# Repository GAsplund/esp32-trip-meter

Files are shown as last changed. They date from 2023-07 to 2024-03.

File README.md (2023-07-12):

# ESP32 Trip Meter
An ESP32-based trip meter primarily made for measuring fuel efficiency.

## Background and motivation
I started this project in search of a solution for measuring the fuel efficiency on my '97 Volvo 940.
The only real solution I found prior was the [MPGuino](http://mpguino.wiseman.ee/eng), but I quickly realised it wasn't for my needs.
What I wanted was to have a solution that was as clean as possible, so having a separate display that I had to mount somewhere was out of the question.

Instead, I built it around a standard Bluetooth OBD-II interface, which would allow any device to get information and display it in any way they want.
This was perfect for my use case, as I wanted to display all the information on my phone or Android stereo via the [Torque](https://play.google.com/store/apps/details?id=org.prowl.torque) app.

## Features
- Measure fuel efficiency (L/100km)
- Measure velocity (Km/h)
- Measure fuel injection speed (L/h)
- Display data through an emulated ELM327 (OBD-II) interface

## Connections
- The negative side of the injector is connected to corresponding input on the board
  - NOTE: Must be a saturation-type injector (read below)
- A pulsed signal of the vehicle speed sensor (VSS) is connected to VSS+
  - Variable reluctance (VR) speed sensors do not seem to work

### Power and ground
The ground reference and power is currently given by the USB port on the ESP32.
This may change later due to being a limiting factor.

## Injector types
This project is mainly made to support saturation-type injectors.
If your engine uses other types of injectors, such as peak-and-hold injectors, this project **will not work**.

The easiest way to check this is to measure the resistance of an injector;
If it has a resistance of around 12Ω, it is a saturation-type injector.
If it has a resistance of around 2-3Ω, it is likely a **peak-and-hold** injector.

**Also note that** injectors that are connected for batch injection may be connected in parallel, and may in some cases display a resistance that is lower than normal.

The reason why peak-and-hold injectors will not work, is that they work differently from saturation injectors.
While saturation injectors simply open while the signal is active, a peak-and-hold injector, like its name suggests, sends a high voltage signal which forces the injector open (peak).
After that, a lower-voltage signal (normally around 12 volts) is pulsed through the remainder of the opening time (hold).

## Platform compatibility
Since the project currently uses ESP32-specific platform code a lot, it would be difficult to port to using normal Arduino implementations.
It may be possible to port it to ESP8266 devices, but they would need a discrete Bluetooth module.

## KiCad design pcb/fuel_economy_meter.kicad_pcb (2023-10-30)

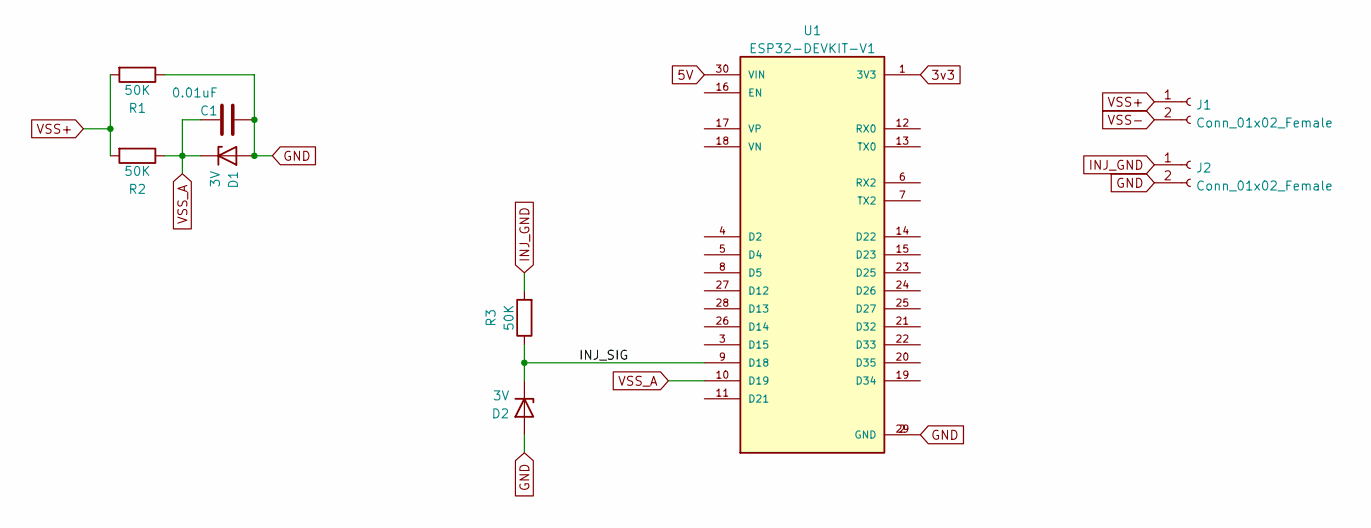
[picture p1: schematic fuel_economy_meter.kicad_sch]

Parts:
C1: 0.01uF; C_1206_3216Metric_Pad1.33x1.80mm_HandSolder
D1, D2: 3V; D_SOD-123
J1, J2: Conn_01x02_Female; JST_XH_B2B-XH-A_1x02_P2.50mm_Vertical
R1, R2, R3: 50K; R_1206_3216Metric_Pad1.30x1.75mm_HandSolder
U1: ESP32-DEVKIT-V1; MODULE_ESP32_DEVKIT_V1; PARTREV N/A

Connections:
3v3: U1.1 (3V3)
5V: U1.30 (VIN)
/INJ_SIG: D2.1 (K), R3.1, U1.9 (D18)
GND: C1.2, D1.2 (A), D2.2 (A), J2.2, R1.1, U1.2 (GND), U1.29 (GND)
INJ_GND: J2.1, R3.2
VSS+: J1.1, R1.2, R2.2
VSS-: J1.2
VSS_A: C1.1, D1.1 (K), R2.1, U1.10 (D19)

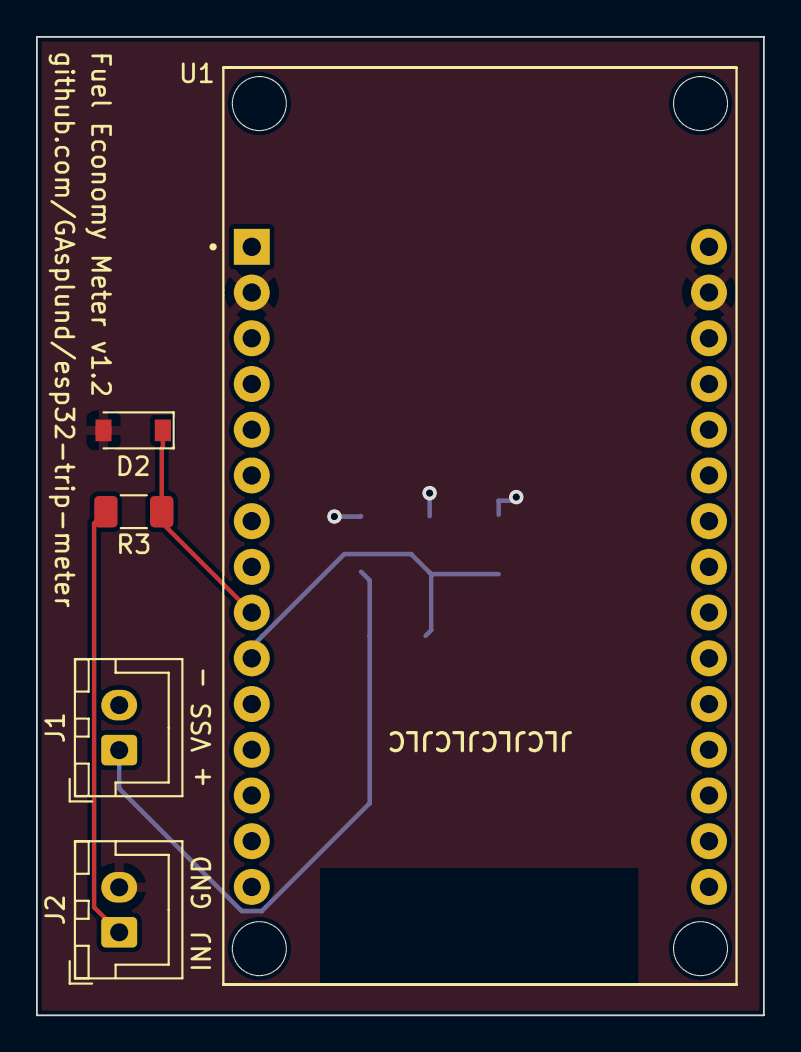
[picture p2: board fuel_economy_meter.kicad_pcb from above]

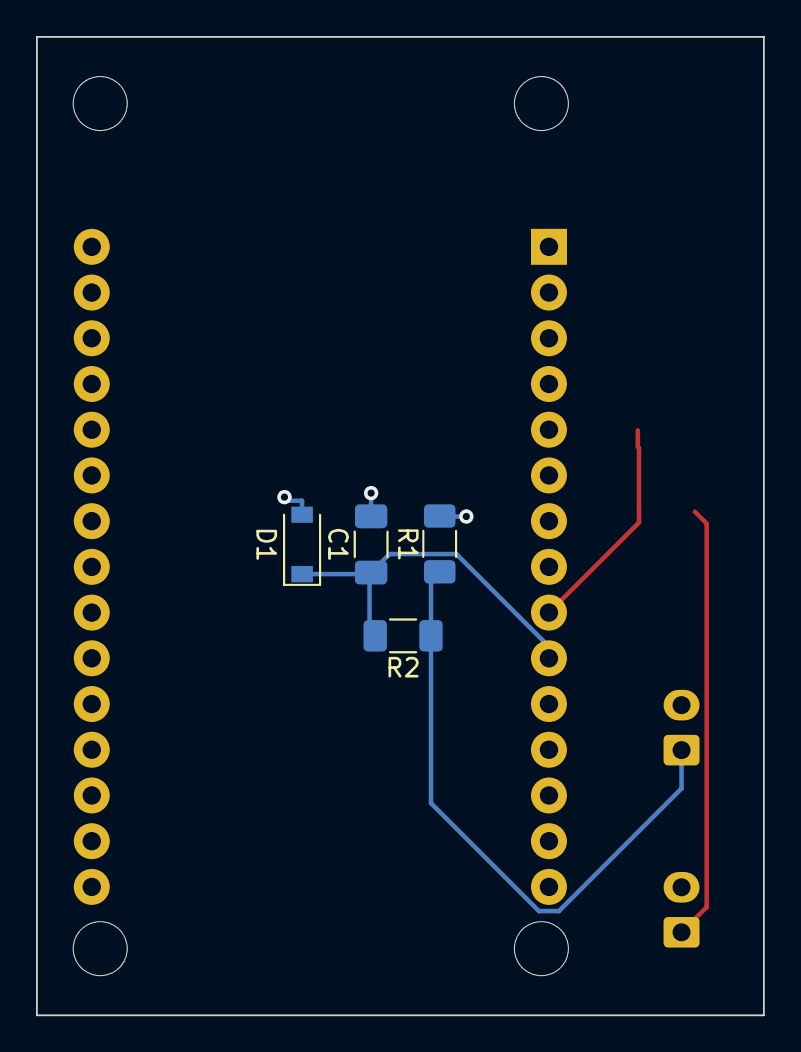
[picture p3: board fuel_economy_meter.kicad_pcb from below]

Board: 2 copper layers, 40.4 x 54.4 mm, 9 parts (4 on the bottom side), 5 nets.

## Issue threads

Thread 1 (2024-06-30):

Esp32 crashes after couple seconds of reading

gangster-unicorn, 2024-06-30:
Im currently Testing this in on my old but trusted bmw r1200gs from 2004. I'm printing the readings via the Logstream function. Its looks like its reading the injector fine. When i give gas the L/h starts rising. But after about 1 minute of reading it looks like the esp32 crashes and i have to cycle the power to get it to start logging again. Any thoughts? I'm using the esp32 wroom

GAsplund, 2024-06-30:
Hi, thanks for testing it out! I've been developing on an ESP32-wroom myself, so differing hardware should not be an issue.

Regarding the freeze, it sounds like the watchdog is triggering for some reason. Previous times where I've had this happen it would crash and require a manual reset. You can try checking if this is the case for you by using a baud rate of 115200 and running until it crashes or freezes. Hopefully it will print a stacktrace showing what's wrong.

gangster-unicorn, 2024-06-30:
Hi, thanks for the fast response.

Somehow changing the baudrate to 115200 its not crashing anymore. thanks for helping me out! One more question, i notice that a lot of the time it does not register the rpm only the injection time. Is this expected behaviour?

GAsplund, 2024-06-30:
My guess is that a lower baud rate causes printing along with the interrupts to starve the watchdog timer. Glad to hear that increasing it solved the issue!
The calculation for RPM should work as long as the injectors are being measured properly. If the injection period changes at all between prints, that should be the case.

gangster-unicorn, 2024-07-04:
Thanks for all the help turns out i was using the wrong zener diodes 5v instead of 3v now everything works properly!

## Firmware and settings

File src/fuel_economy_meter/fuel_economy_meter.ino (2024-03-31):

#include "trip.h"
#include "bt.h"
#include "elm327.h"
#include "log_stream.h"

static Trip trip;
static ELM327 elm327;
//static LogStream logStream;

void setup()
{
  Serial.begin(9600);
  Serial.println("BT");
  setupBT();
  Serial.println("Trip");
  trip.begin();
  elm327.begin(&SerialBT, &trip);
  //Serial.println("LogStream");
  //logStream.begin(&Serial, &trip);

  Serial.println("Setup done");
}

void loop()
{
  //delay(1000);
  //logStream.log();
  elm327.poll();
}

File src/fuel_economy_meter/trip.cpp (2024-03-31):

#include "trip.h"

#include <arduino.h>
#include "esp_timer.h"
#include "config.h"
#include "soc/mcpwm_reg.h"
#include "soc/mcpwm_struct.h"
#include "driver/mcpwm.h"
#include "driver/timer.h"

#define APB_TICK_US(ticks) ((ticks) / (APB_CLK_FREQ / 1000000))

Trip *sTrip = 0;

/**
 * Starts the VSS interrupts and adds interrupts for the injector and VSS sensor
 */
void Trip::begin(void)
{
  sTrip = this;

  Serial.println("Setting up timers");
  timer_init(TIMER_GROUP_0, TIMER_0, &timeout_timer_conf);
  timer_init(TIMER_GROUP_0, TIMER_1, &timeout_timer_conf);
  timer_set_counter_value(TIMER_GROUP_0, TIMER_0, INJ_TICKS_TIMEOUT);
  timer_set_counter_value(TIMER_GROUP_0, TIMER_1, VSS_TICKS_TIMEOUT);
  timer_isr_callback_add(TIMER_GROUP_0, TIMER_0, &Trip::timeoutInjISR, NULL, 0);
  timer_isr_callback_add(TIMER_GROUP_0, TIMER_1, &Trip::timeoutVssISR, NULL, 0);

  Serial.println("Setting up injector ISR");
  gpio_set_pull_mode(INJ_GPIO, GPIO_PULLUP_ONLY);
  mcpwm_gpio_init(MCPWM_UNIT_0, MCPWM_CAP_0, INJ_GPIO);
  mcpwm_gpio_init(MCPWM_UNIT_0, MCPWM_CAP_1, INJ_GPIO);
  mcpwm_capture_enable(MCPWM_UNIT_0, MCPWM_SELECT_CAP0, MCPWM_NEG_EDGE, 0);
  mcpwm_capture_enable(MCPWM_UNIT_0, MCPWM_SELECT_CAP1, MCPWM_POS_EDGE, 0);
  mcpwm_isr_register(MCPWM_UNIT_0, Trip::tripInjISRHandler, NULL, ESP_INTR_FLAG_IRAM, NULL);

  Serial.println("Setting up VSS ISR");
  gpio_set_pull_mode(VSS_GPIO, GPIO_PULLUP_ONLY);
  mcpwm_gpio_init(MCPWM_UNIT_1, MCPWM_CAP_0, VSS_GPIO);
  mcpwm_gpio_init(MCPWM_UNIT_1, MCPWM_CAP_1, VSS_GPIO);
  mcpwm_capture_enable(MCPWM_UNIT_1, MCPWM_SELECT_CAP0, MCPWM_NEG_EDGE, 0);
  mcpwm_capture_enable(MCPWM_UNIT_1, MCPWM_SELECT_CAP1, MCPWM_POS_EDGE, 0);
  mcpwm_isr_register(MCPWM_UNIT_1, Trip::tripVssISRHandler, NULL, ESP_INTR_FLAG_IRAM, NULL);

  Serial.println("Starting timers");
  timer_start(TIMER_GROUP_0, TIMER_0);
  timer_start(TIMER_GROUP_0, TIMER_1);
}

/**
 * @brief Handles a pulse in the injector signal
 *
 * Used to calculate total and momentary injection time.
 * Injector is considered open when the signal is low due to MOSFET pulling it down.
 * 
 *     ╭―(+ Inj -)―╮
 *     +           o - pull-down signal
 *     |           |
 *     -           / - ECU MOSFET
 *     ╰―――――――――――╯
 */
void Trip::injPulse(uint32_t openCap, uint32_t closeCap)
{
  timer_set_counter_value(TIMER_GROUP_0, TIMER_0, INJ_TICKS_TIMEOUT);

  // Make sure that the injector has been open before
  // We also don't know how many times we could have 
  // overflowed before, so we discard any additional captures
  if (this->latestInjectionTimestamp == 0)
  {
    this->latestInjectionTimestamp = openCap;
    return;
  }

  uint32_t dutyTime = openCap > closeCap ?
    (0xFFFFFFFF - openCap) + closeCap + 1:
    closeCap - openCap;

  if (dutyTime <= INJ_DELTA_MAX)
  {
    this->latestInjectionDutyTime = APB_TICK_US(dutyTime);
    this->latestInjectionPeriod = APB_TICK_US(openCap - this->latestInjectionTimestamp);
  }
  
  this->latestInjectionTimestamp = openCap;
}

void IRAM_ATTR Trip::tripInjISRHandler(void* arg)
{
  if (MCPWM0.int_st.cap1_int_st && sTrip != 0)
    sTrip->injPulse(mcpwm_capture_signal_get_value(MCPWM_UNIT_0, MCPWM_SELECT_CAP0), mcpwm_capture_signal_get_value(MCPWM_UNIT_0, MCPWM_SELECT_CAP1));
  
  MCPWM0.int_clr.val = MCPWM0.int_st.val;
}

/**
 * @brief Handles a pulse in the VSS signal
 *
 * Uses the length of the pulse to calculate the velocity of the vehicle.
 * If the time since the last pulse isn't too long, the pulse is considered to be valid.
 */
void Trip::vssPulse(uint32_t upCap, uint32_t downCap)
{
  timer_set_counter_value(TIMER_GROUP_0, TIMER_1, VSS_TICKS_TIMEOUT);
  this->totalVssPulses++;

  if(isStopped)
  {
    isStopped = false;
    return;
  }

  // We assume that the HIGH time is always half a period
  uint32_t period = 2 * (upCap > downCap ?
    (0xFFFFFFFF - upCap) + downCap + 1:
    downCap - upCap);

  if (period < VSS_DELTA_MAX)
    this->latestVssPeriod = APB_TICK_US(period);
}

void IRAM_ATTR Trip::tripVssISRHandler(void* arg)
{
  if (MCPWM1.int_st.cap1_int_st && sTrip != 0)
    sTrip->vssPulse(mcpwm_capture_signal_get_value(MCPWM_UNIT_1, MCPWM_SELECT_CAP0), mcpwm_capture_signal_get_value(MCPWM_UNIT_1, MCPWM_SELECT_CAP1));
  
  MCPWM1.int_clr.val = MCPWM1.int_st.val;
}

/**
 * @brief Handles a timeout in the injector signal
 *
 * Used to calculate the total RPM of the engine.
 * If the injector has not opened for a long time, the engine is considered to be stopped.
 */
void Trip::timeoutInj()
{
  this->latestInjectionPeriod = 0;
  this->latestInjectionDutyTime = 0;
  this->latestInjectionTimestamp = 0;
}

bool IRAM_ATTR Trip::timeoutInjISR(void*)
{
  Serial.println("Inj timeout");
  if (sTrip != 0)
    sTrip->timeoutInj();
  return false;
}

/**
 * @brief Handles a timeout in the VSS signal
 *
 * Used to calculate the total velocity of the vehicle.
 * If the VSS signal has not pulsed for a long time, the vehicle is considered to be stopped.
 */
void Trip::timeoutVss()
{
  this->latestVssPeriod = 0;
  this->isStopped = true;
}

bool IRAM_ATTR Trip::timeoutVssISR(void*)
{
  Serial.println("VSS timeout");
  if (sTrip != 0)
    sTrip->timeoutVss();
  return false;
}

/**
 * @brief Calculates current engine RPM
 *
 * Uses injector pulse period to calculate the rotation speed of the engine in RPM
 *
 * Given that one single injector fires per engine rotation, the RPM is calculated
 * by dividing 60 seconds by the injector pulse period.
 *
 * Since f = 1/T, the formula is 60/T
 * This implicitly converts from rotations per second (Hz) to rotations per minute.
 * Since the injector pulse period is in microseconds, we multiply by 1e6 to get seconds.
 *
 * @return the current engine RPM
 */
//uint16_t Trip::getRpm(void) { return (this->latestInjectionPeriod > 0) ? (60 * 1000000) / this->latestInjectionPeriod : 0; }
uint_fast16_t Trip::getRpm(void) { return (this->latestInjectionPeriod > 0) ? 60000000 / this->latestInjectionPeriod : 0; }

/**
 * Calculates the total fuel spent
 */
float Trip::getLiters(void) { return this->totalInjectionTime * (1 / INJ_USEC_LITER); }

/**
 * @brief Calculates the duty cycle on the injector
 */
float Trip::getDuty(void) { return (this->latestInjectionPeriod > 0) ? (float) this->latestInjectionDutyTime / (float) this->latestInjectionPeriod : 0; }

/**
 * @brief Calculates momentary fuel consumption
 */
//float Trip::getLph(void) { return (3.6E9 * getDuty()) / INJ_USEC_LITER; }
float Trip::getLph(void) { return (3600000000.0f / INJ_USEC_LITER) * getDuty(); }

/**
 * Calculates the total distance traveled in km
 */
float Trip::getKm(void) { return this->totalVssPulses * (1 / VSS_PULSE_KM); }

/**
 * Calculates the velocity in km/h
 */
float Trip::getKmh(void) { return (this->latestVssPeriod > 0) ? (this->getVel() / VSS_PULSE_KM) * 3600 : 0; }
//float Trip::getKmh(void) { return (esp_timer_get_time() - this->latestVssTimestamp > VSS_DELTA_MAX) ? 0 : ( 3600/VSS_PULSE_KM ) * this->getVel(); }
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

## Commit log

2023-07-12 Import project
    [fuel_economy_meter.kicad_pcb, fuel_economy_meter.kicad_sch, fuel_economy_meter.sch]
2023-08-02 Remove VR sensor circuit
    [fuel_economy_meter.kicad_pcb, fuel_economy_meter.kicad_sch]
2023-08-05 Formatting, get velocity from signal period
    ISR functions are now based on the latest instantiated Trip class
2023-08-05 Calculate total trip properly, fix ISR arguments
    [trip.cpp]
2023-10-24 Don't use strapping pin for injector signal
    [fuel_economy_meter.kicad_pcb, fuel_economy_meter.kicad_sch]
2023-10-27 Explicit types, avoid float division
    This shaves off a good amount of CPU cycles here and there.
    Since the ESP32 FPU doesn't have division, this is done in software.
    GCC doesn't simplify division by a constant into multiplication
    without using flags, so multiplication is done explicitly in code
    where possible.
    Also specifying a floating point value implicitly makes it double
    precision, which in many cases caused a sign extension, only for
    it to be turned back into single precision before being returned.
    [trip.cpp]
2023-10-30 Consolidate component designators
    [fuel_economy_meter.kicad_pcb, fuel_economy_meter.kicad_sch]
